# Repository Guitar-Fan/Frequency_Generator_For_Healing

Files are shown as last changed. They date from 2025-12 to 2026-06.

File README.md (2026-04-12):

# AFG Health Theremin

This is the AFG (adjustable frequency generator) Health Theremin using an Teensy 4.0 development board's built in DSP library for synthesizing audio. It produces precise audio frequencies and waveforms for all sorts of health needs, such as sleeping, meditating, or even studying. The device offers a touchscreen, customizable frequency selection, waveform generation. With 2 ToF sensors, this project functions as a Theremin, an instrument played by moving your hand closer or further from the instrument. I designed a feature to custom draw a waveform on the touchscreen to hear what sound it produces. All electronics are neatly housed in a custom-designed 3D-printed enclosure.

I made this project because I love music and sound, and wanted to make a project dedicated to my music passion that is useful at the same time. It is particularly helpful for personal meditation, sound therapy, or group sessions in remote locations. It is also fun to play and experiment with the audio synthesis capabilities.

## Images

### 3D Model
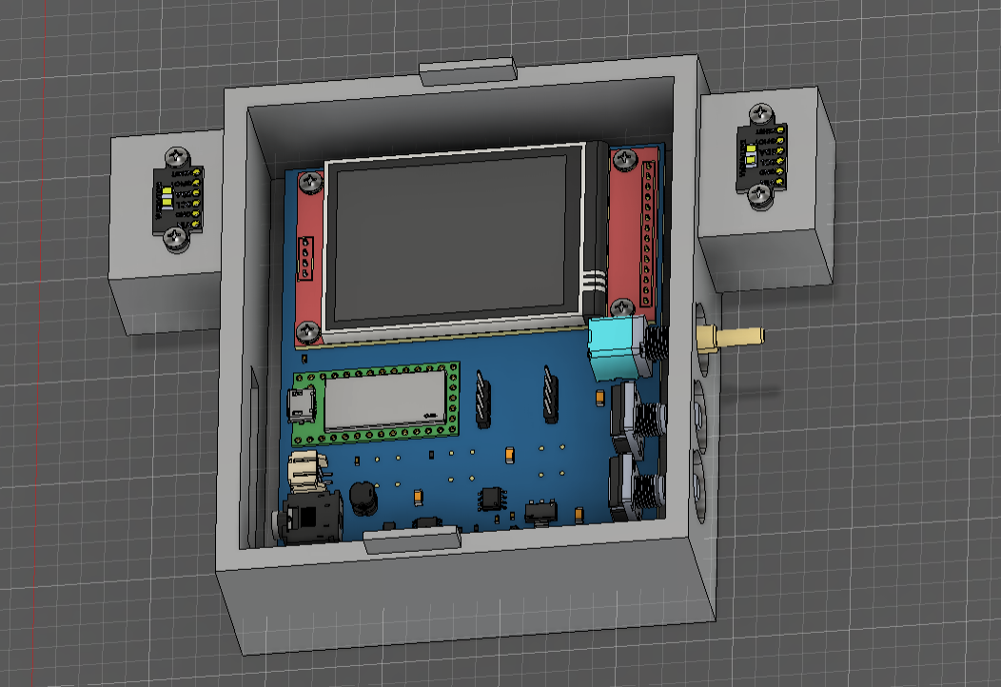
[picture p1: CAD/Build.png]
3D Build Model with Enclosure

*Custom-designed 3D-printed enclosure for the frequency generator*

### PCB Design
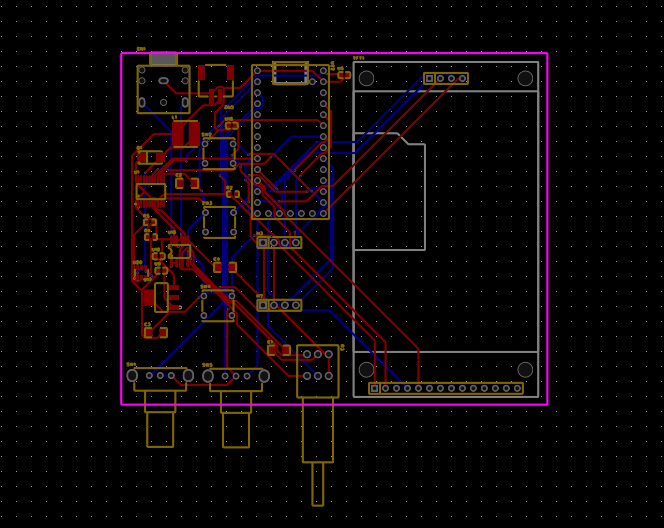
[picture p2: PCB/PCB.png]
PCB Layout

*Custom PCB design for the frequency generator circuit*

### Wiring Diagram
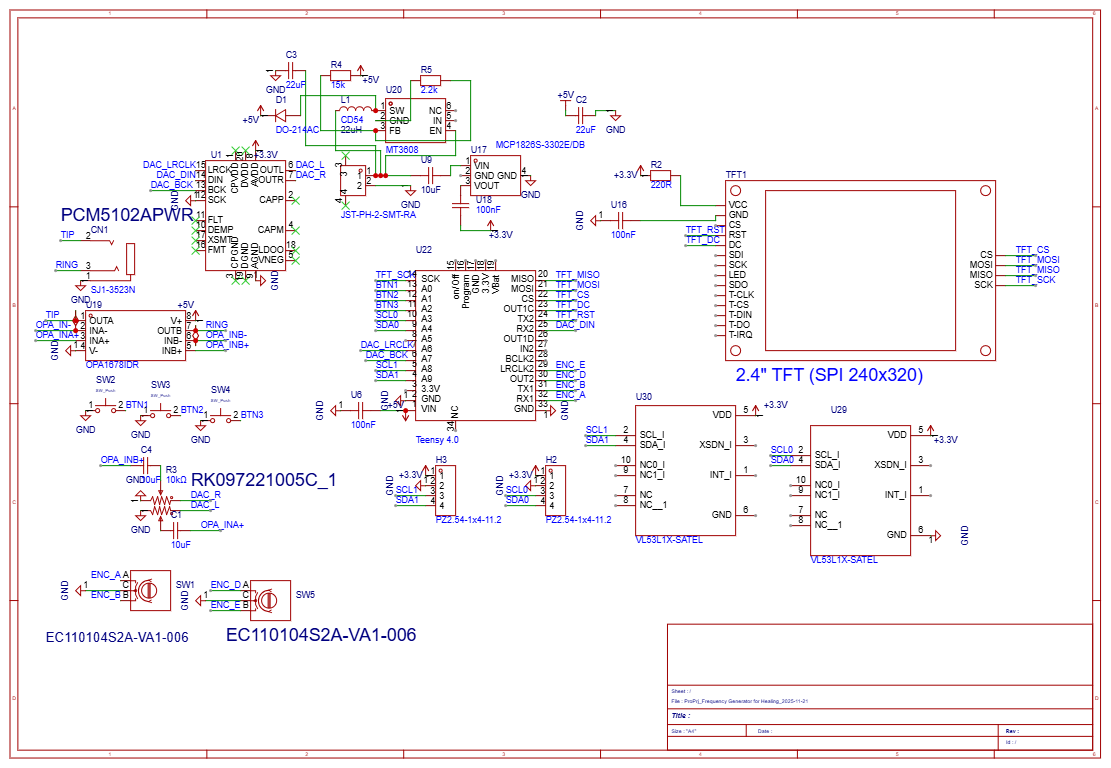
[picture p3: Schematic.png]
Wiring Diagram

*Complete wiring diagram showing all connections*

## Bill of Materials (BOM)

The complete Bill of Materials is available in the following formats:
- [CSV Format](BOM/BOM_AFG_Theremin%20-%20BOM_ProPrj_Frequency%20Generator%20%20-%20Copy%20of%20BOM_AFG_Theremin%20-%20BOM_ProPrj_Frequency%20Generator%20.csv)
- [Interactive HTML BOM](BOM/InteractiveBOM_PCB2_2026-1-7.html)

### BOM Summary

| Name | Purpose | Quantity | Total | Links | Distributor |
|---|---|---|---|---|---|
| 10uF | Multilayer Ceramic Capacitors MLCC - SMD/SMT | 2 | 0 | https://www.digikey.com/en/products/detail/kemet/C1206X106J3RACTU/7427565 | Digikey |
| 22uF | Multilayer Ceramic Capacitors MLCC - SMD/SMT | 2 | 0 | https://www.digikey.com/en/products/detail/yageo/CC1206MKX5R8BB226/7164406 | Digikey |
| SJ1-3523N | Audio Connectors | 1 | 0 | https://www.digikey.com/en/products/detail/same-sky-formerly-cui-devices/SJ1-3523N/738689 | Digikey |
| JST-PH-2-SMT-RA |  | 1 | 0 | https://www.digikey.com/en/products/detail/jst-sales-america-inc/S2B-PH-K-S/926626 | Digikey |
| DO-214AC |  | 1 | 0 | https://www.digikey.com/en/products/detail/smc-diode-solutions/S1G/6022594 | Digikey |
| CD54 |  | 1 | 0 | https://www.digikey.com/en/products/detail/sumida-america-inc/CD54NP-220MC/2108185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 | Digikey |
| 220R |  | 1 | 0 | https://www.digikey.com/en/products/detail/stackpole-electronics-inc/RMCF0603FT220R/1760809 | Digikey |
| 10kΩ | Potentiometers, Variable Resistors | 1 | 0 | https://www.aliexpress.us/item/3256805258177673.html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 | Aliexpress |
| 15k |  | 1 | 0 | https://www.digikey.com/en/products/detail/stackpole-electronics-inc/RMCF0603FT15K0/1760774 | Digikey |
| 2.2k |  | 1 | 0 | https://www.digikey.com/en/products/detail/yageo/RC0603FR-072K2L/727016 | Digikey |
| EC110104S2A-VA1-006 |  | 2 | 0 | https://www.digikey.com/en/products/detail/alps-alpine/EC11E18244AU/19529126 | Digikey |
| Switch_SW_Push |  | 3 | 0 | exclude | exclude |
| 2.4" TFT (SPI 240x320) |  | 1 | 0 | https://www.ebay.com/itm/204415217707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 | Ebay |
| PCM5102APWR |  | 1 | 0 | https://www.digikey.com/en/products/detail/texas-instruments/PCM5102APWR/3727211 | Digikey |
| 100nF |  | 3 | 0 | https://www.digikey.com/en/products/detail/yageo/CC0603KRX7R7BB104/302822 | Digikey |
| C0603 |  | 1 | 0 | https://www.digikey.com/en/products/detail/yageo/CC0603KRX5R5BB106/5195190 | Digikey |
| MCP1826S-3302E/DB | Voltage Regulators - Linear, Low Drop Out (LDO) Regulators | 1 | 0 | https://www.digikey.com/en/products/detail/microchip-technology/MCP1826S-3302E-DB/1635997 | Digikey |
| OPA1678IDR | Operational Amplifier | 1 | 0 | https://www.digikey.com/en/products/detail/texas-instruments/OPA1678IDR/7034940 | Digikey |
| TEENSY 4.0 |  | 1 | 0 | https://www.digikey.com/en/products/detail/sparkfun-electronics/16997/13158150 | Digikey |
| Pin Header 2.54-1x4-11.2 |  | 2 | 0 | https://www.digikey.com/en/products/detail/w-rth-elektronik/61300411121/4846827 | Digikey |
| MT3608 | DC-DC Converters | 1 | 0 | https://www.aliexpress.us/item/3256809007855182.html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 | Aliexpress |
| VL53L1X |  | 2 | 0 | https://www.aliexpress.us/item/3256803076438500.html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 | Aliexpress |
| Digikey | Digikey | 1 | $63.09 | Digikey | Digikey |
| Aliexpress | Aliexpress | 1 | 24.15 | Aliexpress | Aliexpress |
| JCLPCB | JCLPCB | 1 | 5.3 | JCLPCB | JCLPCB |
| EBAY | EBAY | 1 | 17.36 | EBAY | EBAY |

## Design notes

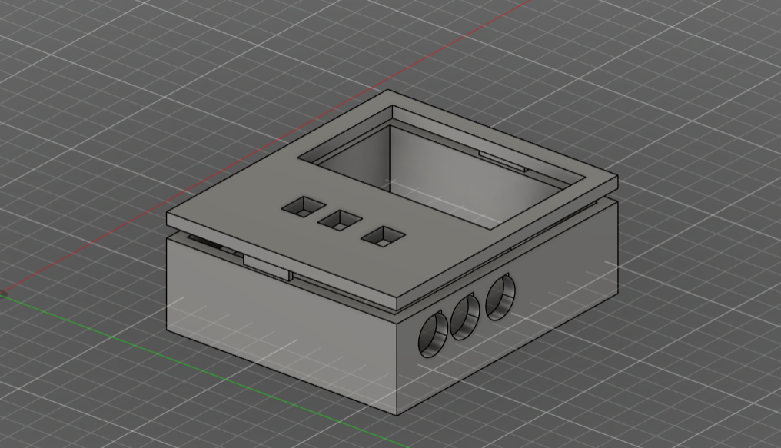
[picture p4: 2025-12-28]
CAD/Enclosure.png

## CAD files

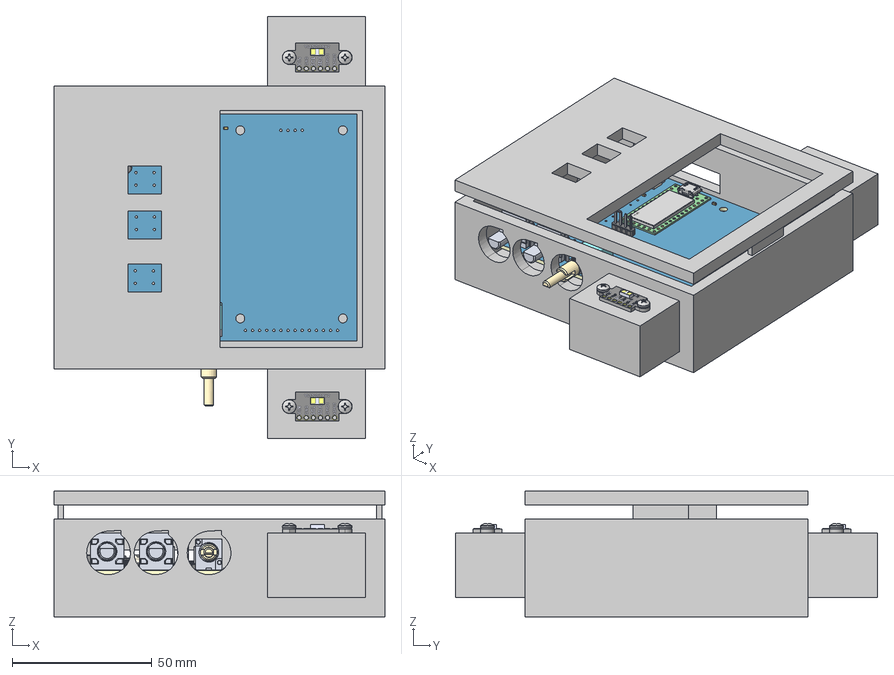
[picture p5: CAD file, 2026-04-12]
CAD/3D_PCB2_AdjFreqGen.step
118.5 x 151.3 x 45.0 mm
92000A201_Passivated 18-8 Stainless Steel Pan Head Phillips Screws x 4

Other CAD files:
3D_PCB2_AdjFreqGen.f3z

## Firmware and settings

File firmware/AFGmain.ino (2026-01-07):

#include <Wire.h>
#include <SPI.h>
#include <Audio.h>
#include <SD.h>
#include <SerialFlash.h>
#include <VL53L1X.h>
#include <ILI9341_t3.h>
#include <XPT2046_Touchscreen.h>

// ==========================================
//              PIN DEFINITIONS
// ==========================================
// Display Pins (Check your specific wiring!)
#define TFT_DC      9
#define TFT_CS      10
#define TFT_RST     8   // Or 255 if connected to 3.3V
#define TFT_MOSI    11
#define TFT_SCK     13
#define TFT_MISO    12
#define TOUCH_CS    6   // Chip select for Touch
#define TOUCH_IRQ   255 // We will use polling, not IRQ

// Button Pins
#define BTN_MODE    4
#define BTN_ACTION  5

// ==========================================
//           AUDIO SYSTEM SETUP
// ==========================================
// Audio Design Tool Graph:
// Waveform -> Mixer -> I2S Output
AudioSynthWaveform       waveform1; 
AudioMixer4              mixer1; 
AudioOutputI2S           i2s1; 
AudioConnection          patchCord1(waveform1, 0, mixer1, 0);
AudioConnection          patchCord2(mixer1, 0, i2s1, 0);
AudioConnection          patchCord3(mixer1, 0, i2s1, 1); // Stereo output

// Array for "Custom Drawn" Waveform (256 samples is standard)
short waveTable[257]; 

// ==========================================
//           SENSOR & HARDWARE SETUP
// ==========================================
VL53L1X sensorPitch;
VL53L1X sensorVol;

// Display & Touch Objects
ILI9341_t3 tft = ILI9341_t3(TFT_CS, TFT_DC, TFT_RST, TFT_MOSI, TFT_SCK, TFT_MISO);
XPT2046_Touchscreen ts(TOUCH_CS, TOUCH_IRQ);

// Logic Variables
int currentMode = 0; // 0 = Theremin, 1 = Draw Wave
float smoothedPitch = 440.0;
float smoothedVol = 0.0;
unsigned long lastVizUpdate = 0;

// ==========================================
//                SETUP
// ==========================================
void setup() {
  Serial.begin(9600);
  
  // 1. Setup Audio Memory
  AudioMemory(20);
  
  // 2. Setup Audio Waveform Defaults
  waveform1.begin(WAVEFORM_SINE);
  waveform1.frequency(440);
  waveform1.amplitude(1.0); // We control volume via Mixer, not Waveform amp
  
  // 3. Setup Buttons
  pinMode(BTN_MODE, INPUT_PULLUP);
  pinMode(BTN_ACTION, INPUT_PULLUP);

  // 4. Setup Display
  tft.begin();
  tft.setRotation(3); // Landscape
  tft.fillScreen(ILI9341_BLACK);
  tft.setTextColor(ILI9341_WHITE);
  tft.setTextSize(2);
  tft.setCursor(10, 10);
  tft.print("System Booting...");
  
  ts.begin();
  ts.setRotation(3);

  // 5. Setup Sensors (THE DUAL I2C TRICK)
  
  // --- Pitch Sensor on Wire (Pins 18/19) ---
  Wire.begin();
  Wire.setClock(400000); // 400kHz I2C
  sensorPitch.setBus(&Wire);
  sensorPitch.setTimeout(500);
  if (!sensorPitch.init()) {
    tft.setCursor(10, 30); tft.print("Pitch Sensor Fail!");
  }
  sensorPitch.setDistanceMode(VL53L1X::Medium);
  sensorPitch.setMeasurementTimingBudget(20000); // 20ms fast response
  sensorPitch.startContinuous(20);

  // --- Volume Sensor on Wire1 (Pins 16/17) ---
  Wire1.begin();
  Wire1.setClock(400000);
  sensorVol.setBus(&Wire1);
  sensorVol.setTimeout(500);
  if (!sensorVol.init()) {
    tft.setCursor(10, 50); tft.print("Vol Sensor Fail!");
  }
  sensorVol.setDistanceMode(VL53L1X::Medium);
  sensorVol.setMeasurementTimingBudget(20000);
  sensorVol.startContinuous(20);

  // Initialize Custom Waveform array to a flat line
  for (int i=0; i<257; i++) {
    waveTable[i] = 0;
  }
  
  delay(1000);
  drawInterface();
}


void loop() {
  
  // --- Button Handling ---
  if (digitalRead(BTN_MODE) == LOW) {
    currentMode++;
    if (currentMode > 1) currentMode = 0;
    drawInterface();
    delay(300); // Debounce
  }

  // --- Mode 0: THEREMIN PERFORMANCE ---
  if (currentMode == 0) {
    runTheremin();
  }
  // --- Mode 1: DRAW WAVEFORM ---
  else if (currentMode == 1) {
    runDrawer();
  }
}

// ==========================================
//           THEREMIN LOGIC
// ==========================================
void runTheremin() {
  // 1. Read Sensors
  sensorPitch.read();
  sensorVol.read();
  
  int dPitch = sensorPitch.ranging_data.range_mm;
  int dVol = sensorVol.ranging_data.range_mm;

  // 2. Map Pitch (Distance -> Hz)
  // Logic: 50mm = 100Hz, 500mm = 1000Hz. 
  // If > 600mm, hold last note or ignore.
  float targetFreq = 0;
  if (dPitch < 600 && dPitch > 30) {
    targetFreq = map(dPitch, 30, 500, 100, 1000);
  } else {
    targetFreq = smoothedPitch; // Hold steady
  }

  // 3. Map Volume (Distance -> Gain 0.0 to 1.0)
  // Logic: Close = Quiet, Far = Loud (Traditional Theremin style)
  // OR: Close = Loud, Far = Quiet (Often easier for beginners) -> Let's do Close=Loud
  float targetVol = 0;
  if (dVol < 400 && dVol > 30) {
    targetVol = map((float)dVol, 30.0, 400.0, 1.0, 0.0);
    // Clamp values
    if (targetVol < 0) targetVol = 0;
    if (targetVol > 1) targetVol = 1;
  } else {
    targetVol = 0; // Silence if hand is gone
  }

  // 4. Smoothing (Low Pass Filter)
  // This removes the "jitter" from the sensors
  smoothedPitch = 0.8 * smoothedPitch + 0.2 * targetFreq;
  smoothedVol = 0.8 * smoothedVol + 0.2 * targetVol;

  // 5. Apply to Audio Engine
  waveform1.frequency(smoothedPitch);
  mixer1.gain(0, smoothedVol);

  // 6. Update Screen (Slowly, 10fps)
  if (millis() - lastVizUpdate > 100) {
    tft.fillRect(60, 100, 200, 40, ILI9341_BLACK); // Clear numbers
    tft.setCursor(60, 100);
    tft.print((int)smoothedPitch); tft.print(" Hz");
    tft.setCursor(60, 120);
    tft.print((int)(smoothedVol*100)); tft.print(" %");
    
    // Draw Bar Graph
    int barH = smoothedVol * 100;
    tft.fillRect(280, 200 - barH, 20, barH, ILI9341_GREEN);
    tft.fillRect(280, 50, 20, 150 - barH, ILI9341_BLACK); // Clear top
    
    lastVizUpdate = millis();
  }
}

// ==========================================
//           WAVE DRAW LOGIC
// ==========================================
void runDrawer() {
  // If "Action" button is pressed, play the drawn wave
  if (digitalRead(BTN_ACTION) == LOW) {
    waveform1.begin(WAVEFORM_ARBITRARY);
    waveform1.arbitraryWaveform(waveTable, 10000); // Apply array
    // Play a test tone
    waveform1.frequency(220);
    mixer1.gain(0, 0.8);
    return; // Skip drawing while playing
  } else {
    // Silence while drawing
    mixer1.gain(0, 0); 
  }

  // Handle Touch
  if (ts.touched()) {
    TS_Point p = ts.getPoint();
    
    // Map Touch Coordinates to Screen/Array
    // Note: Touch mapping often needs calibration numbers (min/max)
    // Adjust these 200/3800 values based on your specific screen calibration!
    int x = map(p.x, 200, 3800, 0, 320); 
    int y = map(p.y, 200, 3800, 0, 240);

    // If touch is inside the drawing box
    if (x > 10 && x < 266 && y > 50 && y < 200) {
      int index = x - 10; // 0 to 255
      
      // Map Y (height) to Audio Sample (-32000 to +32000)
      // Screen Y 50 is Top (+32000), Y 200 is Bottom (-32000)
      int sampleVal = map(y, 50, 200, 30000, -30000);
      
      waveTable[index] = sampleVal;
      
      // Draw pixel
      tft.drawPixel(x, y, ILI9341_YELLOW);
      // Erase pixels above/below to clean up
      tft.drawFastVLine(x, 50, y-50, ILI9341_BLACK);
      tft.drawFastVLine(x, y+1, 200-y, ILI9341_BLACK);
    }
  }
}

// ==========================================
//               UI HELPER
// ==========================================
void drawInterface() {
  tft.fillScreen(ILI9341_BLACK);
  
  if (currentMode == 0) {
    tft.setCursor(10, 10);
    tft.setTextColor(ILI9341_GREEN);
    tft.print("MODE: THEREMIN");
    
    tft.drawRect(50, 80, 220, 80, ILI9341_WHITE);
    tft.setCursor(60, 200);
    tft.setTextColor(ILI9341_WHITE);
    tft.print("Pitch: Left | Vol: Right");
  } 
  else {
    tft.setCursor(10, 10);
    tft.setTextColor(ILI9341_YELLOW);
    tft.print("MODE: DRAW WAVE");
    
    // Draw Box
    tft.drawRect(9, 49, 258, 152, ILI9341_BLUE);
    tft.setCursor(10, 210);
    tft.print("Touch to draw.");
    tft.setCursor(10, 225);
    tft.print("Hold BTN2 to play.");
    
    // Set standard wave to arbitrary so it's ready
    waveform1.begin(WAVEFORM_ARBITRARY);
  }
}

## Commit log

2025-12-28 Upload files and started readme
    [3D_Enclosure_AdjFreqGen.3mf, BOM_ProPrj_Frequency Generator for Healing_2025-11-21_PCB2_2025-12-26 - BOM_ProPrj_Frequency Generator .csv]
2025-12-28 bom update
    [BOM_ProPrj_Frequency Generator for Healing_2025-11-21_PCB2_2025-12-26 - BOM_ProPrj_Frequency Generator .csv]
2026-01-04 update files
    [BOM_ProPrj_Frequency Generator for Healing_2025-11-21_PCB2_2025-12-26 - BOM_ProPrj_Frequency Generator (2).csv, BOM_ProPrj_Frequency Generator for Healing_2025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]
2026-04-12 cad, image, bom
    [3D_Enclosure_FreqGenTheremin.3mf, 3D_PCB2_AdjFreqGen.step, AFG_Theremin_3dAssembly.step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]
